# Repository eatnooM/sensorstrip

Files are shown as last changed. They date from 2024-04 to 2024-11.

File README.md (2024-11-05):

# sensorstrip

Image of PCBs

License: CC BY-SA 4.0

An IR LED emitter setup, for use with the Wii or IR-based light guns with a focus on remaining as slim as possible, with no components on the back of the board to allow mounting directly to a display

Image of board mounted on a TV

## Board

Grab the gerbers from [the latest release](https://github.com/eatnooM/sensorstrip/releases/latest) and upload to your favourite PCB fab ([OSHPark](https://oshpark.com/), [Aisler](https://aisler.net/), [JLCPCB](https://jlcpcb.com/)). Default settings should be fine - I wouldn't recommend getting the boards any thinner than 1.6mm as may restrict your mounting options.

HASL is a-ok to use and generally the cheapest option, so would recommend this as the surface finish.

## Assembly

### Tools required
- Soldering iron
- Solder (recommend relatively thin solder - this will make it easier to avoid bridging pins by adding too much)
- Flux (will help keep your joints shiny and happy)
- Tweezers
- Wire crimping tool (if not buying preassembled cables)

Assembly is possible with just an iron, but be super sure to get the USB-C and Molex Picoblade connectors correctly aligned before you tin more than one pad - they're tricky to fix mistakes on without hot air or a hot plate.

### What do I need?

There are a few options that will work for any given setup but I'll outline the ones most likely to be appealing

Wii / 2IR light guns only:
- 1x [power-emitter](/sensorstrip-power-emitter) + 1x [emitter](/sensorstrip-emitter)
- 1x [power-4ir](/sensorstrip-power-4ir) + 2x [emitter](/sensorstrip-emitter) (you can skip populating 2 Picoblade connectors)

4IR light guns only (Gun4IR / OpenFIRE):
- 1x [power-emitter](/sensorstrip-power-emitter) + 3x [emitter](/sensorstrip-emitter)
- 1x [power-4ir](/sensorstrip-power-4ir) + 4x [emitter](/sensorstrip-emitter)

Wii / 2IR light guns *and* 4IR light guns in square layout (OpenFIRE):
- 1x [power-42-square](/sensorstrip-power-42-square) + 4x [emitter](/sensorstrip-emitter)

Wii / 2IR light guns *and* 4IR light guns in diamond layout (Gun4IR):
- 1x [power-42-diamond](/sensorstrip-power-42-diamond) + 6x [emitter](/sensorstrip-emitter)

### Steps - Wii Sensor bar (power-emitter + emitter)

I swear I'll flesh this out later but here's how I'd go about soldering up the simplest setup of power-emitter + emitter. Any other setup is basically more of the same.

- First, solder the USB connector to J1 onto the power-emitter board. If using an iron, I'd tin one of the outer pads and move the port into place while keeping this molten (without lingering too long, of course!) - Once you're happy with the alignment, add a little solder to the other pads. Be sure plenty to get good strong joints on the shielding - these will be providing the bulk of the mechanical strength keeping the port in place. If you bridge any pads, try adding some flux and introducing a nice clean iron tip.
- Add the Molex connectors to both boards - J2 on the power-emitter, J1 on the emitter. Similar to the USB port, I've had most success lining up one of the pads, then once aligned properly move onto the mounting points and then the remaining pad.
	- You don't need to populate J2 on an emitter board unless you're connecting additional emitters through it
	- In this revision, emitter boards have swapped polarity between the 'Power in' and 'Power out' Picoblade connectors; this is to ensure you can use the pre-made cable assemblies that do not cross over the wires. If you choose to crimp your own cables, be sure to account for this.
- Add the resistors, and the F1 on the power-emitter board. Tin a single pad and introduce the component, then add solder to the other side. If you're using a tip with significant thermal mass, don't hang about for long; you may melt the solder on the other side _through_ the component. An 0603 resistor will happily float away with the surface tension on your iron and make a new home on it.
	- I'd strongly recommend populating R2 and R3 (5.1K) on the power-emitter board as they'll allow USB C to C cables to be used but if this isn't important to you, feel free to omit them.
- Add the LEDs. The LEDs can be soldered flat against the board so they stick out of the front (recommended when mounting under a display), or through-hole (can help if mounting emitters around the edge of a really thin display). The pad labelled with an A is for the anode (positive) leg. If you're using LEDs with a shallow viewing angle, you may want to angle the outer LEDs slightly to increase effective viewing angles but the SFH 4547 are fine firing straight outwards.
- Lastly, add the switch to the power-emitter board. Handily, orientation does not matter!
	- Alternatively, you can bridge the jumper J1 with a blob of solder to force the board to be always on when plugged in. If you anticipate a total power draw over over 600mA, you might want to do this as you'd be exceeding the switch's rating otherwise (300mA per pole - they're both tied together on this PCB).

Once you're done, plug in your cable between the Power out of the power-emitter board and the Power in on the emitter anddddd fingers crossed, you have light! The IR LEDs in the BOM aren't visible to the naked eye, so you may want to use a phone to test (I've heard iPhones like to filter IR out, though)

## Shells

If you want a nice enclosure to keep things looking tidy, RayneX has made [some brilliant shells](https://www.printables.com/model/1063020-sensorstrip-led-emitter-shell-for-openfire-gun4ir) on Printables.

There are enclosures for the emitter boards and the power-42-square board (which should also fit the latest revision of the power-4ir board, but this is untested at present).

## TODO
- Take some nice pictures of common setups
- Video showing assembly? Ugh

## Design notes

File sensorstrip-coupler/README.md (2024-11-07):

# sensorstrip-coupler

These boards are just to allow use of the premade Molex cables where >600mm length is required by joining two cables together.

## BOM

You're not gonna believe this

| Reference | Part desc / number | Notes |
|---|---|---|
| J1, J2 | Molex 53261-0271  - [Mouser](https://www.mouser.com/ProductDetail/Molex/53261-0271?qs=%252B72YyncTwW%252B8%252BBjraxGf3A%3D%3D) | |

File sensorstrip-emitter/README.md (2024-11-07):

# sensorstrip-emitter

The crux of the project - a small, simple board to hold some IR LEDs. Any build will include at least one of these.

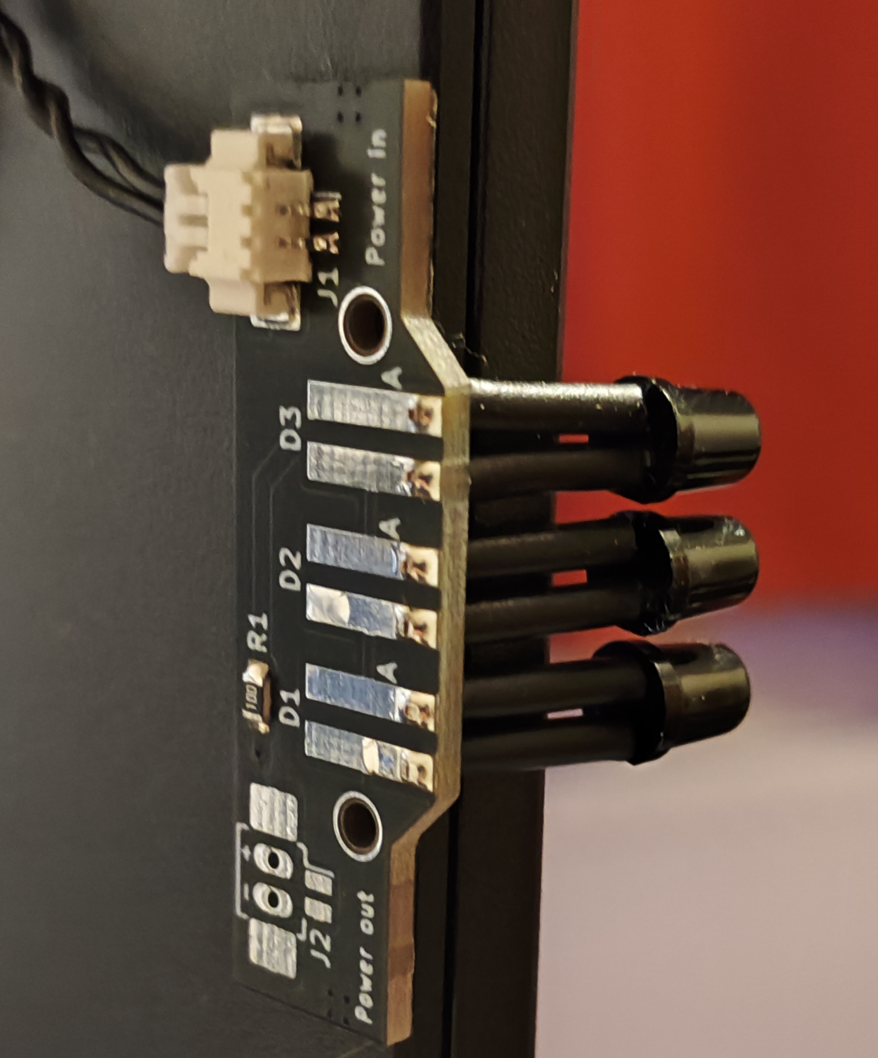
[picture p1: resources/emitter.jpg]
Image of emitter board


As well as these, you will need something to supply power. Any of the boards with 'power' in their name can handle this.

## BOM

| Reference | Part desc / number | Notes |
|---|---|---|
| J1, J2 | Molex 53261-0271  - [Mouser](https://www.mouser.com/ProductDetail/Molex/53261-0271?qs=%252B72YyncTwW%252B8%252BBjraxGf3A%3D%3D) | J2 can be omitted if not daisy chaining |
| D1-3 | IR LED - 940nm - [Mouser](https://www.mouser.com/ProductDetail/720-SFH4547) |  |
| R1 | 7-120R 0805 - [Mouser](https://www.mouser.com/ProductDetail/YAGEO/RC0805FR-0710RL?qs=8Y8p%252BasKcI5T5bn0nqNRsw%3D%3D) / [LCSC](https://www.lcsc.com/product-detail/Chip-Resistor-Surface-Mount_YAGEO-RC0805FR-0710RL_C96347.html)  | Value depends on your LEDs - 7-10R work well with SFH-4547 |

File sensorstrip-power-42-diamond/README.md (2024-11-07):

# sensorstrip-power-42-diamond

You'd have to be quite mad to use this board. Here's a picture of mine:

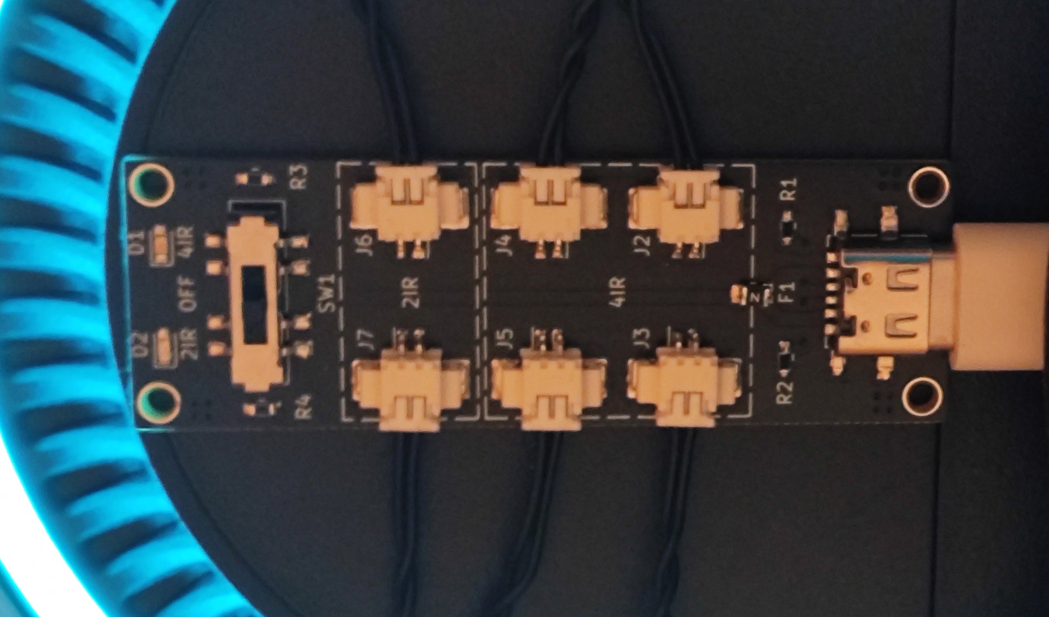
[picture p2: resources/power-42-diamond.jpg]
Image of power-42-diamond board


A board that will take 5V from its USB-C board with 3 power states:

- Off
- 2IR (for Wii or 2IR-based light guns)
- 4IR (for light guns supporting square layouts)

This board is great if you use one display for both Wii gameplay and light gun games.

You'll need *6* emitter boards to make full use of this power board, as the diamond layout doesn't contain a usable sensor bar layout.

## BOM

| Reference | Part desc / number | Notes |
|---|---|---|
| J1 | 6-pin SMD Type C connector - [Mouser](https://www.mouser.co.uk/ProductDetail/GCT/USB4135-GF-A?qs=Li%252BoUPsLEnt6HRo6RUvaXA%3D%3D) / [LCSC](https://lcsc.com/product-detail/USB-Connectors_DEALON-USB-TYPE-C-007_C2927027.html) |  |
| J2-J7 | Molex 53261-0271  - [Mouser](https://www.mouser.com/ProductDetail/Molex/53261-0271?qs=%252B72YyncTwW%252B8%252BBjraxGf3A%3D%3D) | |
| - | Picoblade Cable assembly - [Preassembled - Mouser (60cm length)](https://www.mouser.com/ProductDetail/Molex/15134-0206?qs=F%2F1Z9SgJL%252BXkfyBT%252BHsQcw%3D%3D) / [LCSC - housing](https://www.lcsc.com/product-detail/_MOLEX-_C293613.html) + [LCSC - terminal](https://www.lcsc.com/product-detail/_MOLEX-_C259763.html) | Need one of these for each emitter board |
| F1 | 0805 PTC - [Mouser](https://www.mouser.com/ProductDetail/Murata-Electronics/PRG21BC0R2MM1RA?qs=makukexe9nzHJ%252Bvxp0S09w%3D%3D) / [LCSC](https://www.lcsc.com/product-detail/_Murata-Electronics-_C184863.html) | Overcurrent protection |
| D1 | Status LED - [Mouser](https://www.mouser.co.uk/ProductDetail/Wurth-Elektronik/150060GS75000?qs=LlUlMxKIyB0UYkq5lDO8nA%3D%3D) / [LCSC](https://www.lcsc.com/product-detail/Light-Emitting-Diodes-LED_Everlight-Elec-19-217-GHC-YR1S2-3T_C72043.html) | Optional |
| D2 | Status LED - [Mouser](https://www.mouser.co.uk/ProductDetail/Lite-On/LTST-C190KFKT?qs=6QHXI9jVcTyVErVIqD1vhg%3D%3D) / [LCSC](https://www.lcsc.com/product-detail/Light-Emitting-Diodes-LED_BrtLed-Bright-LED-Elec-BL-HKC36G-AV-TRB_C165981.html) | |
| R1,R2 | 5.1K 0603 - [Mouser](https://www.mouser.com/ProductDetail/Panasonic/ERJ-3EKF5101V?qs=MVjVSMjNRMqhyossZ5oXsQ%3D%3D) / [LCSC](https://lcsc.com/product-detail/Chip-Resistor-Surface-Mount_PANASONIC-ERJ3EKF5101V_C123727.html) | Required if powering from C-C cable |
| R3, R4 | 1K 0603 - [Mouser](https://www.mouser.co.uk/ProductDetail/Panasonic/ERJ-3EKF1001V?qs=H7k1u0Mp9JTM8yQxOuvoDg%3D%3D) / [LCSC](https://www.lcsc.com/product-detail/Chip-Resistor-Surface-Mount_YAGEO-RC0603FR-071KL_C22548.html) | Required for status LED |
| SW1 | DPDT - [Mouser](https://www.mouser.co.uk/ProductDetail/CK/JS203011SCQN?qs=JjVGa%2FzevDlOFy51fkl7ZQ%3D%3D) / [LCSC](https://www.lcsc.com/product-detail/Slide-Switches_Korean-Hroparts-Elec-K3-2336S-F1_C223869.html) | |

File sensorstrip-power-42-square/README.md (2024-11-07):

# sensorstrip-power-42-square

This board is only useful if you use 4IR light guns supporting a square LED layout (effectively, top + bottom sensor bars). At present, this is only true of [the OpenFIRE project](https://openfirelightgun.org/)

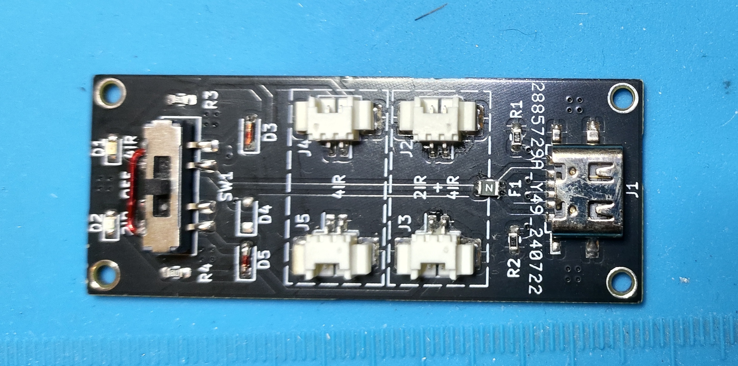
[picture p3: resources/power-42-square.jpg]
Image of power-42-square board


A board that will take 5V from its USB-C board with 3 power states:

- Off
- 2IR (for Wii or 2IR-based light guns)
- 4IR (for light guns supporting square layouts)

These boards are ideal if you use one display for both Wii gameplay and light gun games.

You'll need 4 emitter boards to make full use of this power board.

## BOM
| Reference | Part desc / number | Notes |
|---|---|---|
| J1 | 6-pin SMD Type C connector - [Mouser](https://www.mouser.co.uk/ProductDetail/GCT/USB4135-GF-A?qs=Li%252BoUPsLEnt6HRo6RUvaXA%3D%3D) / [LCSC](https://lcsc.com/product-detail/USB-Connectors_DEALON-USB-TYPE-C-007_C2927027.html) |  |
| J2-J5 | Molex 53261-0271  - [Mouser](https://www.mouser.com/ProductDetail/Molex/53261-0271?qs=%252B72YyncTwW%252B8%252BBjraxGf3A%3D%3D) | |
| - | Picoblade Cable assembly - [Preassembled - Mouser (60cm length)](https://www.mouser.com/ProductDetail/Molex/15134-0206?qs=F%2F1Z9SgJL%252BXkfyBT%252BHsQcw%3D%3D) / [LCSC - housing](https://www.lcsc.com/product-detail/_MOLEX-_C293613.html) + [LCSC - terminal](https://www.lcsc.com/product-detail/_MOLEX-_C259763.html) | Need one of these for each emitter board |
| F1 | 0805 PTC - [Mouser](https://www.mouser.com/ProductDetail/Murata-Electronics/PRG21BC0R2MM1RA?qs=makukexe9nzHJ%252Bvxp0S09w%3D%3D) / [LCSC](https://www.lcsc.com/product-detail/_Murata-Electronics-_C184863.html) | Overcurrent protection |
| D1 | Status LED - [Mouser](https://www.mouser.co.uk/ProductDetail/Wurth-Elektronik/150060GS75000?qs=LlUlMxKIyB0UYkq5lDO8nA%3D%3D) / [LCSC](https://www.lcsc.com/product-detail/Light-Emitting-Diodes-LED_Everlight-Elec-19-217-GHC-YR1S2-3T_C72043.html) | Optional |
| D2 | Status LED - [Mouser](https://www.mouser.co.uk/ProductDetail/Lite-On/LTST-C190KFKT?qs=6QHXI9jVcTyVErVIqD1vhg%3D%3D) / [LCSC](https://www.lcsc.com/product-detail/Light-Emitting-Diodes-LED_BrtLed-Bright-LED-Elec-BL-HKC36G-AV-TRB_C165981.html) | |
| R1,R2 | 5.1K 0603 - [Mouser](https://www.mouser.com/ProductDetail/Panasonic/ERJ-3EKF5101V?qs=MVjVSMjNRMqhyossZ5oXsQ%3D%3D) / [LCSC](https://lcsc.com/product-detail/Chip-Resistor-Surface-Mount_PANASONIC-ERJ3EKF5101V_C123727.html) | Required if powering from C-C cable |
| R3, R4 | 1K 0603 - [Mouser](https://www.mouser.co.uk/ProductDetail/Panasonic/ERJ-3EKF1001V?qs=H7k1u0Mp9JTM8yQxOuvoDg%3D%3D) / [LCSC](https://www.lcsc.com/product-detail/Chip-Resistor-Surface-Mount_YAGEO-RC0603FR-071KL_C22548.html) | Required for status LED |
| SW1 | DPDT - [Mouser](https://www.mouser.co.uk/ProductDetail/CK/JS203011SCQN?qs=JjVGa%2FzevDlOFy51fkl7ZQ%3D%3D) / [LCSC](https://www.lcsc.com/product-detail/Slide-Switches_Korean-Hroparts-Elec-K3-2336S-F1_C223869.html) | |

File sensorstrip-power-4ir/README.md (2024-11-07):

# sensorstrip-power-4ir

A board that will take 5V from its USB-C board to and pass it on to all 4 emitters, with an on-off switch.

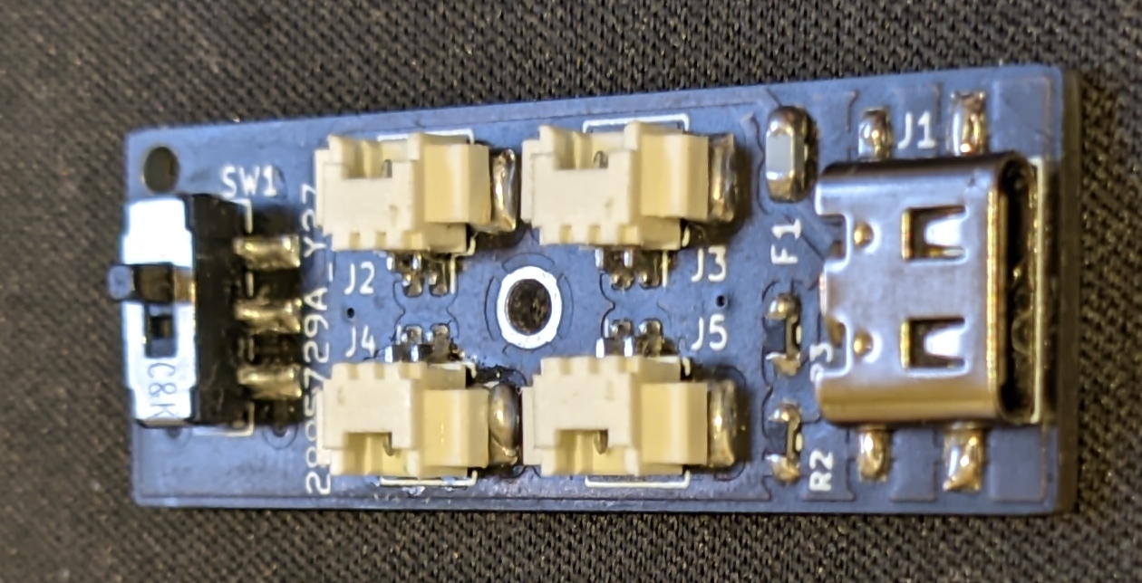
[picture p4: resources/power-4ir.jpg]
Image of power-4ir board

_Old picture - there have been some changes since this picture_

These boards are ideal if you only ever plan to use the emitters with light guns.

## BOM

| Reference | Part desc / number | Notes |
|---|---|---|
| J1 | 6-pin SMD Type C connector - [Mouser](https://www.mouser.co.uk/ProductDetail/GCT/USB4135-GF-A?qs=Li%252BoUPsLEnt6HRo6RUvaXA%3D%3D) / [LCSC](https://lcsc.com/product-detail/USB-Connectors_DEALON-USB-TYPE-C-007_C2927027.html) |  |
| J2-J5 | Molex 53261-0271  - [Mouser](https://www.mouser.com/ProductDetail/Molex/53261-0271?qs=%252B72YyncTwW%252B8%252BBjraxGf3A%3D%3D) | |
| - | Picoblade Cable assembly - [Preassembled - Mouser (60cm length)](https://www.mouser.com/ProductDetail/Molex/15134-0206?qs=F%2F1Z9SgJL%252BXkfyBT%252BHsQcw%3D%3D) / [LCSC - housing](https://www.lcsc.com/product-detail/_MOLEX-_C293613.html) + [LCSC - terminal](https://www.lcsc.com/product-detail/_MOLEX-_C259763.html) | Need one of these for each emitter board |
| F1 | 0805 PTC - [Mouser](https://www.mouser.com/ProductDetail/Murata-Electronics/PRG21BC0R2MM1RA?qs=makukexe9nzHJ%252Bvxp0S09w%3D%3D) / [LCSC](https://www.lcsc.com/product-detail/_Murata-Electronics-_C184863.html) | Overcurrent protection |
| D1 | Status LED - [Mouser](https://www.mouser.co.uk/ProductDetail/Wurth-Elektronik/150060GS75000?qs=LlUlMxKIyB0UYkq5lDO8nA%3D%3D) / [LCSC](https://www.lcsc.com/product-detail/Light-Emitting-Diodes-LED_Everlight-Elec-19-217-GHC-YR1S2-3T_C72043.html) | Optional |
| R1,R2 | 5.1K 0603 - [Mouser](https://www.mouser.com/ProductDetail/Panasonic/ERJ-3EKF5101V?qs=MVjVSMjNRMqhyossZ5oXsQ%3D%3D) / [LCSC](https://lcsc.com/product-detail/Chip-Resistor-Surface-Mount_PANASONIC-ERJ3EKF5101V_C123727.html) | Required if powering from C-C cable |
| R3 | 1K 0603 - [Mouser](https://www.mouser.co.uk/ProductDetail/Panasonic/ERJ-3EKF1001V?qs=H7k1u0Mp9JTM8yQxOuvoDg%3D%3D) / [LCSC](https://www.lcsc.com/product-detail/Chip-Resistor-Surface-Mount_YAGEO-RC0603FR-071KL_C22548.html) | Required for status LED |
| SW1 | DPDT - [Mouser](https://www.mouser.co.uk/ProductDetail/CK/JS202011SCQN?qs=LgMIjt8LuD95JYWxZ7NvZA%3D%3D) / [LCSC](https://lcsc.com/product-detail/Slide-Switches_C-K-JS202011SCQN_C221666.html) | |

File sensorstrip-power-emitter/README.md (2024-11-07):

# sensorstrip-power-emitter

A small and elegant board that will take 5V from its USB-C board to power its own LEDs and pass it on to any other emitter boards in your setup.

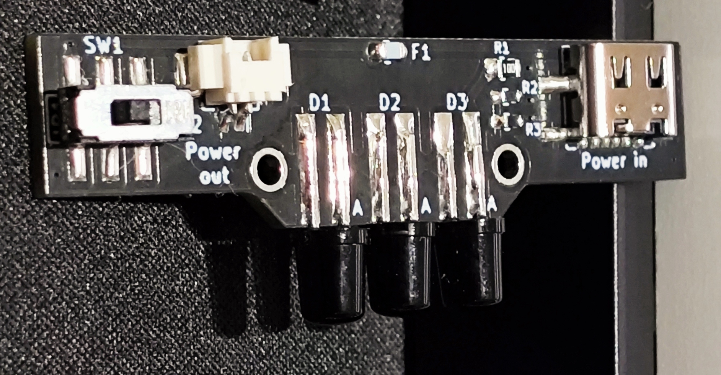
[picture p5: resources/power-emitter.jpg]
Image of power-emitter board

Old picture - there have been some changes since this picture

This board is ideal for the smallest setup possible with no dedicated power board.

## BOM

| Reference | Part desc / number | Notes |
|---|---|---|
| J1 | 6-pin SMD Type C connector - [Mouser](https://www.mouser.co.uk/ProductDetail/GCT/USB4135-GF-A?qs=Li%252BoUPsLEnt6HRo6RUvaXA%3D%3D) / [LCSC](https://lcsc.com/product-detail/USB-Connectors_DEALON-USB-TYPE-C-007_C2927027.html) |  |
| J2 | Molex 53261-0271  - [Mouser](https://www.mouser.com/ProductDetail/Molex/53261-0271?qs=%252B72YyncTwW%252B8%252BBjraxGf3A%3D%3D) | |
| - | Picoblade Cable assembly - [Preassembled - Mouser (60cm length)](https://www.mouser.com/ProductDetail/Molex/15134-0206?qs=F%2F1Z9SgJL%252BXkfyBT%252BHsQcw%3D%3D) / [LCSC - housing](https://www.lcsc.com/product-detail/_MOLEX-_C293613.html) + [LCSC - terminal](https://www.lcsc.com/product-detail/_MOLEX-_C259763.html) | Need one of these for each emitter board |
| F1 | 0805 PTC - [Mouser](https://www.mouser.com/ProductDetail/Murata-Electronics/PRG21BC0R2MM1RA?qs=makukexe9nzHJ%252Bvxp0S09w%3D%3D) / [LCSC](https://www.lcsc.com/product-detail/_Murata-Electronics-_C184863.html) | Overcurrent protection |
| D1-3 | IR LED - 940nm - [Mouser](https://www.mouser.com/ProductDetail/720-SFH4547) |  |
| D4 | Status LED - [Mouser](https://www.mouser.co.uk/ProductDetail/Wurth-Elektronik/150060GS75000?qs=LlUlMxKIyB0UYkq5lDO8nA%3D%3D) / [LCSC](https://www.lcsc.com/product-detail/Light-Emitting-Diodes-LED_Everlight-Elec-19-217-GHC-YR1S2-3T_C72043.html) | Optional |
| R1 | 7-120R 0805 - [Mouser](https://www.mouser.com/ProductDetail/YAGEO/RC0805FR-0710RL?qs=8Y8p%252BasKcI5T5bn0nqNRsw%3D%3D) / [LCSC](https://www.lcsc.com/product-detail/Chip-Resistor-Surface-Mount_YAGEO-RC0805FR-0710RL_C96347.html) | Value depends on your LEDs - 7-10R work well with SFH-4547 |
| R2,R3 | 5.1K 0603 - [Mouser](https://www.mouser.com/ProductDetail/Panasonic/ERJ-3EKF5101V?qs=MVjVSMjNRMqhyossZ5oXsQ%3D%3D) / [LCSC](https://lcsc.com/product-detail/Chip-Resistor-Surface-Mount_PANASONIC-ERJ3EKF5101V_C123727.html) | Required if powering from C-C cable |
| R4 | 1K 0603 - [Mouser](https://www.mouser.co.uk/ProductDetail/Panasonic/ERJ-3EKF1001V?qs=H7k1u0Mp9JTM8yQxOuvoDg%3D%3D) / [LCSC](https://www.lcsc.com/product-detail/Chip-Resistor-Surface-Mount_YAGEO-RC0603FR-071KL_C22548.html) | Required for status LED |
| SW1 | DPDT - [Mouser](https://www.mouser.co.uk/ProductDetail/CK/JS202011SCQN?qs=LgMIjt8LuD95JYWxZ7NvZA%3D%3D) / [LCSC](https://lcsc.com/product-detail/Slide-Switches_C-K-JS202011SCQN_C221666.html) | Optional, but recommended |

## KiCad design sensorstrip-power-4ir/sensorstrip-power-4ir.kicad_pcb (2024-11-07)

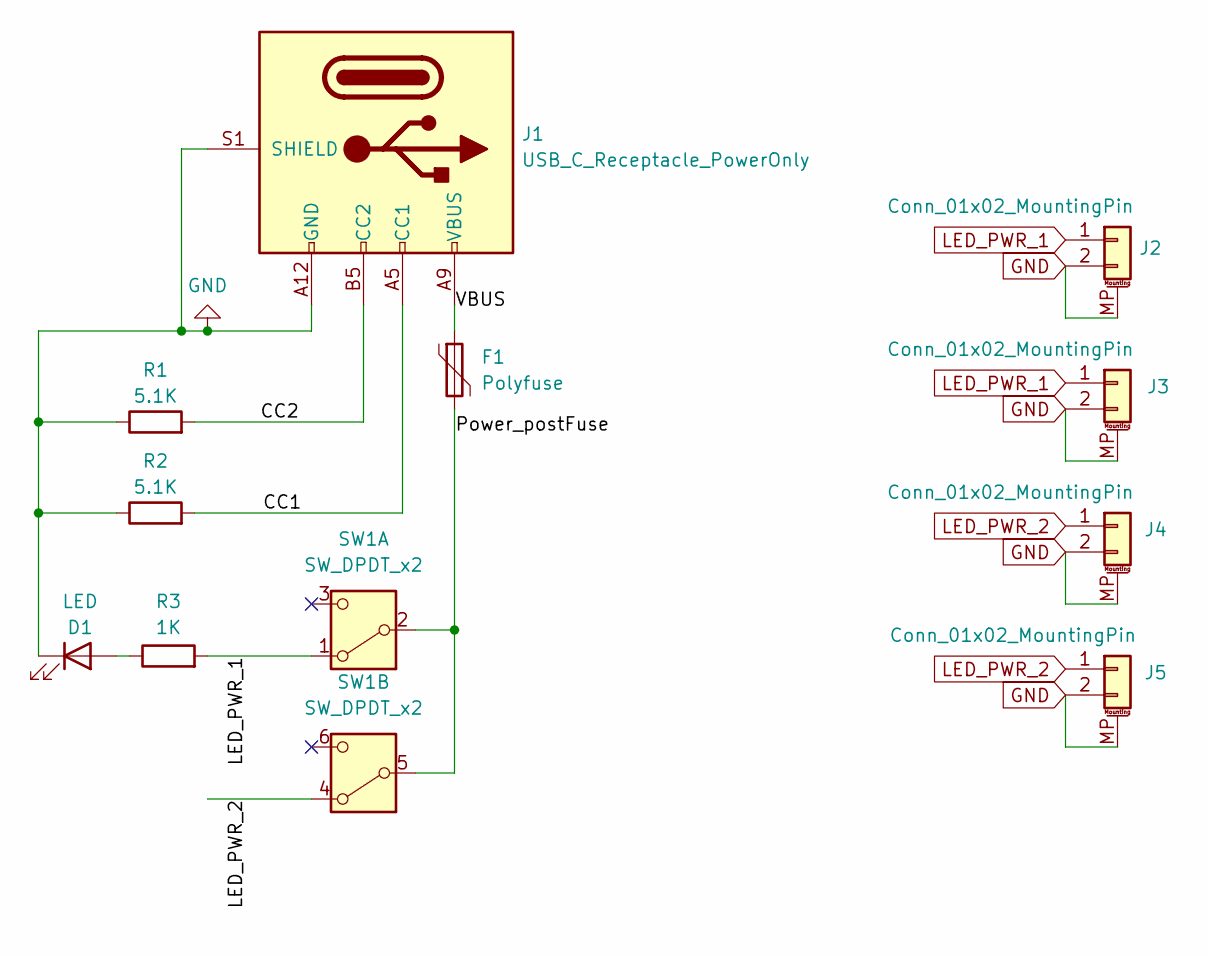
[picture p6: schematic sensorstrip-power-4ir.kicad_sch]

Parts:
D1: LED; LED_0603_1608Metric_Pad1.05x0.95mm_HandSolder
F1: Polyfuse; Fuse_0805_2012Metric_Pad1.15x1.40mm_HandSolder
J1: USB_C_Receptacle_PowerOnly; DEALON USB Type-C 6Pin
J2, J3, J4, J5: Conn_01x02_MountingPin; Molex_Picoblade_53261-0271-Hybrid
R1, R2: 5.1K; R_0603_1608Metric_Pad0.98x0.95mm_HandSolder
R3: 1K; R_0603_1608Metric_Pad0.98x0.95mm_HandSolder
SW1: SW_DPDT_x2; JS202011SCQN-Hybrid-12-PTH

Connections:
/CC1: J1.A5 (CC1), R2.2
/CC2: J1.B5 (CC2), R1.2
/Power_postFuse: F1.2, SW1.2 (B), SW1.5 (B)
/VBUS: F1.1, J1.A9 (VBUS), J1.B9 (VBUS)
GND: D1.1 (K), J1.A12 (GND), J1.B12 (GND), J1.S1 (SHIELD), J2.2, J2.MP (MountPin), J3.2, J3.MP (MountPin), J4.2, J4.MP (MountPin), J5.2, J5.MP (MountPin), R1.1, R2.1
LED_PWR_1: J2.1, J3.1, R3.2, SW1.1 (A)
LED_PWR_2: J4.1, J5.1, SW1.4 (A)
unnamed: D1.2 (A), R3.1

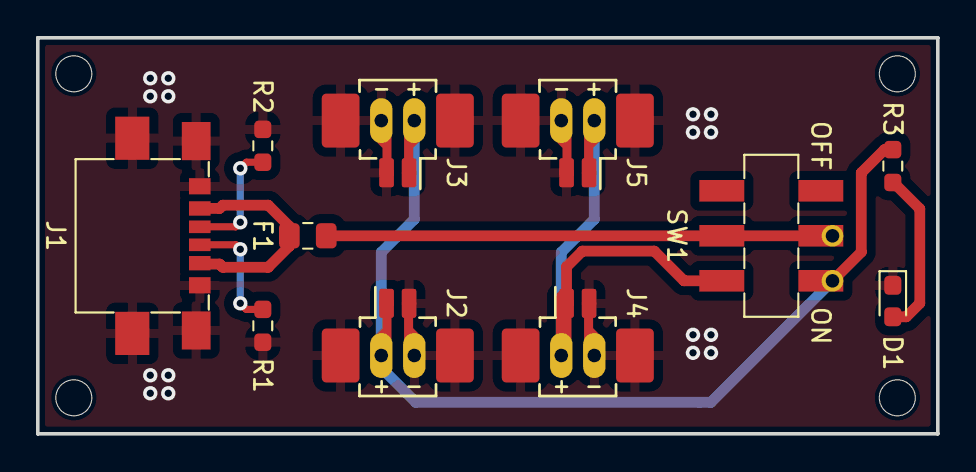
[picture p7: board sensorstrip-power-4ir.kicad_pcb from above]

Board: 2 copper layers, 50.0 x 22.0 mm, 11 parts (0 on the bottom side), 8 nets.

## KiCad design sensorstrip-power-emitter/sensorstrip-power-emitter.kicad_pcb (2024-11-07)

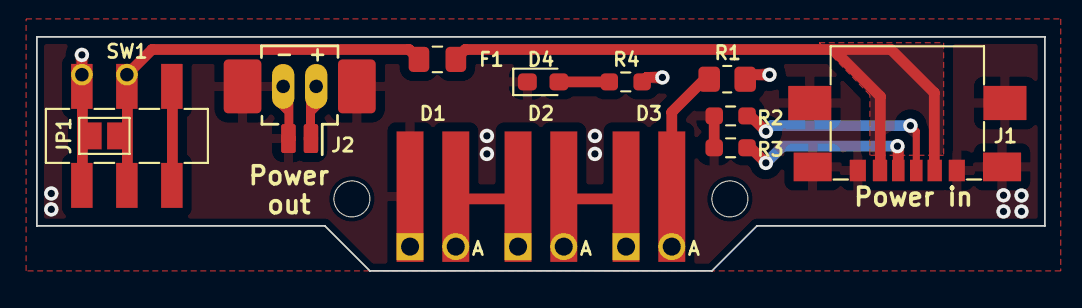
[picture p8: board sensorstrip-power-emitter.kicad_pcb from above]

Board: 2 copper layers, 56.0 x 13.0 mm, 13 parts (0 on the bottom side), 10 nets.

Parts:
D1, D2, D3: LED; LED_THT-1.27mm-OrthogonalSMDAndTHT
D4: LED; LED_0603_1608Metric_Pad1.05x0.95mm_HandSolder
F1: Polyfuse; Fuse_0805_2012Metric_Pad1.15x1.40mm_HandSolder
J1: USB_C_Receptacle_PowerOnly; DEALON USB Type-C 6Pin
J2: Conn_01x02_MountingPin; Molex_Picoblade_53261-0271-Hybrid
JP1: SolderJumper_2_Open; SolderJumper-2_P1.3mm_Open_Pad1.0x1.5mm
R1: 10R; R_0805_2012Metric_Pad1.20x1.40mm_HandSolder
R2, R3: 5.1K; R_0603_1608Metric_Pad0.98x0.95mm_HandSolder
R4: 1K; R_0603_1608Metric_Pad0.98x0.95mm_HandSolder
SW1: SW_DPDT_x2; JS202011SCQN-Hybrid

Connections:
/CC1: J1.A5 (CC1), R2.2
/CC2: J1.B5 (CC2), R3.2
/D1+: D1.2 (A), D2.1 (K)
/D2+: D2.2 (A), D3.1 (K)
/D3+: D3.2 (A), R1.1
/Power_postFuse: F1.2, JP1.2 (B), SW1.2 (B), SW1.5 (B)
/VBUS: F1.1, J1.A9 (VBUS), J1.B9 (VBUS)
GND: D1.1 (K), D4.1 (K), J1.A12 (GND), J1.B12 (GND), J1.S1 (SHIELD), J2.2, J2.MP (MountPin), R2.1, R3.1
unnamed: D4.2 (A), R4.1
Power_postSwitch: J2.1, JP1.1 (A), R1.2, R4.2, SW1.1 (A), SW1.4 (A)

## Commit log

2022-11-01 Initial commit
    Add KiCad files and gerbers
    [sensorstrip.kicad_pcb, sensorstrip.kicad_sch]
2022-11-01 Add sensorstrip-render.png
2022-11-01 Update Readme
    Add quick description and BOM
2022-11-05 Readme: Add Assembly section
2022-11-05 Clean up Assembly section
2022-11-05 Add instructions for ordering boards
2022-11-05 Clarify optional LEDs
2022-11-06 Add mounting and PCB thickness images
2022-11-06 Resize mounting image
2022-11-23 Update to v3
    [sensorstrip.kicad_pcb, sensorstrip.kicad_sch]
2022-11-25 Minor tweaks
    [sensorstrip.kicad_pcb, sensorstrip.kicad_sch]
2022-11-25 Use more appropriate J2 symbol to prevent DRC warning
    [sensorstrip.kicad_pcb, sensorstrip.kicad_sch]
2023-03-25 v3 (#1)
    * v3 (for real this time):
    - Fix huge schematic oversight where LEDs were driven in parallel instead of series
    - Differentiate 'sender' and 'receiver' boards and allow daisy chaining receivers
    - Update LED footprint to allow for more mounting options
    - Swap to Molex Picoblade 53261 connector for ease of assembly
    - Add PTH mounting holes to allow stacking boards for larger LEDs, or mounting with screws
    - Add PPTC for overcurrent protection
    - Update project files to KiCad 7 format
    - Update readme / resources (still some work pending on this)
    [sensorstrip-coupler.kicad_pcb, sensorstrip-coupler.kicad_sch, sensorstrip-power.kicad_pcb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]
2023-09-14 Update BOM
2023-10-08 Update readme and images; tweak sender board CC trace width
    [sensorstrip-sender.kicad_pcb]
2024-04-01 Minor sensorstrip-sender revision:
    - Swap PTH for NPTH
    - Add through-holes to power switch pads for switch relocation
    [sensorstrip-sender.kicad_pcb, sensorstrip-sender.kicad_sch]
2024-04-07 Add 4IR+2IR switchable power board
    Minor cleanup
    [sensorstrip-power-42.kicad_pcb, sensorstrip-power-42.kicad_sch, sensorstrip-receiver.kicad_pcb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]
2024-10-03 Add 2IR/4IR togglable board for square layouts
    [sensorstrip-power-42-square.kicad_pcb, sensorstrip-power-42-square.kicad_sch]
2024-10-30 Update 2/4IR square board for consistent status LED behaviour
    Update DP3T switch footprint to make installing JS203011SCQN easier
    Rename 2IR/4IR diamond layout board for clarity
    [sensorstrip-power-42-diamond.kicad_pcb, sensorstrip-power-42-diamond.kicad_sch, sensorstrip-power-42-square.kicad_pcb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]
2024-10-30 Update 4IR-only power board:
    - Rename for clarity
    - Split IR power across poles for switch longevity
    - Add power LED
    - Use same board layout as 2IR/4IR diamond layout for compatibility
    [sensorstrip-power-4ir.kicad_pcb, sensorstrip-power-4ir.kicad_sch, sensorstrip-power.kicad_pcb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]
2024-10-31 Rename sender / receiver boards to power-emitter and emitter
    ...hopefully this is clearer
    Also some tidying of older boards
    [sensorstrip-coupler.kicad_pcb, sensorstrip-emitter.kicad_pcb, sensorstrip-emitter.kicad_sch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]
2024-11-03 Documentation revamp (#2)
    Split documentation across the pages for each board
    Remove some rambling, add some different rambling
2024-11-03 Add images of each board
2024-11-07 BOM additions (#3)
    Update USB-C connector
    Allowances for GCT USB4135-GF-A footprint
    Update README BOM tables with Mouser links
    [sensorstrip-power-42-diamond.kicad_pcb, sensorstrip-power-42-square.kicad_pcb, sensorstrip-power-4ir.kicad_pcb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]
